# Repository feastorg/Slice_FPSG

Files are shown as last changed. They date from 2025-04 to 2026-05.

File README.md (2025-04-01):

# Slice Template

Template for creating BREAD slices.

## Introduction

[Short introduction on the project.]

## Usage

[Explain how to use the project. Include examples and screenshots if applicable.]

## Documentation

Please refer to the [docs](/docs) for more info.

---

<div align="center">
  <p>
    
    
  </p>
</div>

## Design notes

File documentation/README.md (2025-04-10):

# Docs

Main page for the documentation of the project.

## Schematic Design Notes

Notes on design.

### External Clock

- **Oscillator:** ACO-8.000MHZ-EK

  - 8 MHz XO (Standard) HCMOS, TTL Oscillator, 5V enable/disable
  - Package: 14-DIP, 4 Leads (Metal Can)
  - Product: (See Digikey)
  - Procurement: [Digikey](https://www.digikey.ca/short/9n0brwjd)
  - Datasheet: [Abracon ACO Datasheet](https://abracon.com/Oscillators/ACO.pdf)

- **Connection:**

  - Powered by a dedicated, low-noise 5V rail (from a TPS7A4901 set to 5V)
  - Feed clock output to:
    - ADC’s CLKIN/XTAL1 pin (XTAL2 left unconnected or per datasheet recommendation)
    - Nano Every’s external clock input (D2/PA00 on the ATmega4809)
  - Ensures ADC’s modulator clock and MCU SPI SCLK are synchronous
  - Reference: [Nano Every External Oscillator Info - Arduino Subreddit](https://www.reddit.com/r/arduino/comments/vyi9wo/using_an_external_oscillator_with_the_nano_every/)

    - The onboard programmer on the Nano Every is fully independent and does not rely on bootloaders or clock speed restrictions like the Atmega328-based Arduinos.
    - You don’t need to set fuses via the Arduino IDE; instead, the clock source can be configured at runtime.
    - To change the clock source to external (PA00, Arduino pin D2), use the following code snippet:

      ```
      CPU_CCP = 0xD8;           // Enable writing to protected config registers for the next 4 cycles
      CLKCTRL.MCLKCTRLA = 0x03; // Set clock output off, select external clock source (PA00)
      ```

### Instrumentation Amplifier

- **Amplifier:** AD8426
  - Dual instrumentation amplifier (2 channels per package; use 4 for 8 channels)
  - Product: [AD8426](https://www.analog.com/en/products/ad8426.html)
  - Procurement: [Digikey](https://www.digikey.ca/short/vj3493t8)
  - Datasheet: [AD8426 Datasheet](https://www.analog.com/media/en/technical-documentation/data-sheets/AD8426.pdf)

- **REF Pin:**
  - Maintain low source impedance (<2 Ω recommended)
  - Use a buffered reference (OP1177, see below)

### Analog Reference Voltage Sources

- **Main Regulator (Analog Front End):** TPS7A4901DGNR
  - 150-mA, 36-V, low-noise, high-PSRR adjustable LDO
  - Provides VAA (analog supply) adjustable between ~5V and 10V (up to 12V from a 12V input)
  - Product: [TPS7A4901DGNR](https://www.ti.com/product/TPS7A49/part-details/TPS7A4901DGNR)
  - Procurement: [Digikey](https://www.digikey.ca/short/hr5vft5w)
  - Datasheet: [TPS7A49 Datasheet](https://www.ti.com/lit/ds/symlink/tps7a49.pdf)

- **Clock Regulator:**
  - A second TPS7A4901 (configured to output a fixed 5V) provides the dedicated, low-noise 5VA rail for the external oscillator.

- **Grounding:**
  - Analog ground (gnd_a) is kept separate from digital ground, but tied at a star point.

### Analog Midsupply Voltage Source

- **Reference Buffer:** OP1177 (e.g., OP1177ARMZ)
  - Precision, low-noise op amp used to buffer a resistor divider (with a multi-turn pot) to generate a tunable mid-supply voltage (VREF)
  - Provides a high-impedance reference for the REF pins on the AD8426 amplifiers
  - Product: [OP1177](https://www.analog.com/en/products/op1177.html)
  - Procurement: [Mouser](https://mou.sr/3E6iI69)
  - Datasheet: [OP1177 Datasheet](https://www.analog.com/media/en/technical-documentation/data-sheets/op1177_2177_4177.pdf)

- **Implementation:**
  - Typically one buffered reference can drive all REF pins if layout is good; otherwise, consider one per AD8426.

### Antialiasing Filtering

- Simple RC circuits

### External ADC

- **ADC:** ADS131M08IPBS
  - 24-bit, 32-kSPS, 8-channel simultaneous delta-sigma ADC
  - Product: [ADS131M08](https://www.ti.com/product/ADS131M08)
  - Procurement: [Mouser](https://mou.sr/4j7vdgE)
  - Datasheet: [ADS131M08 Datasheet](https://www.ti.com/lit/ds/symlink/ads131m08.pdf)

### Load Cell

- **MODEL 1914A FEMUR LOAD CELL**
- **Overview:**
  - Provides comprehensive measurements of forces acting on the upper leg just above the knee joint.
  - Features six measurement channels—three forces and three moments—each implemented as a full-bridge strain gauge circuit.
- **Excitation:**
  - Typical excitation is 10 V (nominal), up to 15 V max.
- **Additional Information:**
  - Detailed wiring, specifications, and calibration info are available in the separate Load Cell Datasheet.
  - See [load_cell_specs.md](./load_cell_specs.md) for complete specifications and wiring details (datasheet summary).

### SPI & Data Logging

- **SPI Data Capture:**
  - High-speed SPI data from the ADC is captured by the ATmega4809 (Nano Every)
  - Utilize DMA to transfer data to a buffer
- **Data Logging:**
  - Logging to an SD card (via a high-speed SPI/SDIO interface) and/or real-time USB streaming

## Style Guide

### KiCad Power Symbols Legend

| Power Symbol | Designation | Reference |
| --- | --- | --- |
| +12V | 12V | 12V Source Supply (from the 12V rail on the backplane) |
| GND | GND | Common Ground (from the 12V rail's GND on the backplane) |
| +5V | 5V | Digital 5V Supply (generated by the buck converter for digital circuits) |
| +5VA | 5VA | Dedicated 5V Supply for the external clock oscillator (low-noise LDO output) |
| VAA | VAA | Analog Front-End Supply (adjustable, 5–10V, for sensor conditioning, amps) |
| VPP-->VMID | VMID | _Renamed VPP symbol to VMID._ Mid-Supply Reference Voltage (buffered via OP1177 for instrumentation amps) |
| GNDA | AGND | Analog Ground (for sensor, amps, ADC; tied at star point with DGND) |
| GNDD | DGND | Digital Ground (connected to common ground through heatsink pad) |

### KiCad Colors Legend

| Color  | Value | Reference |
| --- | --- | --- |
| Red | red3 | Analog 5V Supply (e.g., for amps, ADC, references) |
| Brown  | orange1  | Analog Ground (sensor/amp/ADC ground) |
| Orange | orange3  | Digital 5V Supply (MCU, digital circuits) |
| Black  | black | Digital Ground (MCU ground) |
| Pink | magenta3 | 12V Source Supply (from 12V rail on backplane) |
| Blue | blue3 | Clock Signals (oscillator, ADC CLKIN, SPI SCLK) |
| Green  | green3 | Analog Signals (amp outputs to ADC + inputs) |
| Yellow | yellow3  | SPI Control (CS, SYNC/RESET, etc.) |
| Purple | #A020F0  | Special/Reference/Control Signals |
| Grey | gray2 | Miscellaneous/Unassigned |
| Teal | cyan2 | Template/Backplane Connections |

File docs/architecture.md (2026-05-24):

---
title: "Architecture"
description: "Hardware and firmware architecture overview."
---

# Architecture

## Hardware

Full-bridge Precision Strain Gauge (PSG) amplifier/conditioning slice (4-layer PCB). Uses AD8426 instrumentation amplifier with TPS7A4901 precision regulator.

## Firmware

_Not yet developed._

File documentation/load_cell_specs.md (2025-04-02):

# Load Cell Datasheet Details (Model 1914A Femur Load Cell)

**Issue Date:** 5 December 2002

**Models:**  
1914A (and related models: HII 50M, HIII 95LM, HIII 50M, HIII 5F, THOR, BioSID, SID, EuroSID-1, SID-IIs, ES-2)  
_Note: Models 1914V and 1914 Femur Load Cells are identical except for bridge resistance._

- We have 1914A

**Applications:**

- Measures forces on the upper leg above the knee joint
- Useful for occupant protection systems (e.g., knee bolsters)
- Adaptable via removable/replacement end caps
- Contains six measurement channels: three forces and three moments
- Two 30-foot (9.15 m), 12-conductor, Teflon insulated, shielded cables exit the load cell (one for force channels, one for moment channels)
- With aluminum end caps (part #5632), can be used in the ES-2

**Specifications:**

| Channel | Capacity (Metric) | Capacity (English) | Bridge Resistance (1914) | Bridge Resistance (1914A) | Bridge Resistance (1914V) | Sensitivity (mv/v) |
| --- | --- | --- | --- | --- | --- | --- |
| Fx | 13,344.7 N | 3,000 lb | 350 Ω | 350 Ω | 120 Ω | 1.8 |
| Fy | 13,344.7 N | 3,000 lb | 350 Ω | 350 Ω | 120 Ω | 1.8 |
| Fz | 22,241.1 N | 3,000 lb | 480 Ω | 700 Ω | 120 Ω | 1.2 |
| Mx | 338.9 Nm | 3,000 in-lb | 350 Ω | 350 Ω | 120 Ω | 1.5 |
| My | 338.9 Nm | 3,000 in-lb | 350 Ω | 350 Ω | 120 Ω | 1.5 |
| Mz | 338.9 Nm | 3,000 in-lb | 700 Ω | 700 Ω | 240 Ω | 2.6 |

- **Nonlinearity:** < 1% of full scale
- **Hysteresis:** < 1% of full scale
- **Crosstalk:** < 5% of full scale
- **Excitation:** 10 VDC nominal, up to 15 VDC max
- **Mass:** 1.043 kg (2.3 lb)

**Wiring (per channel group):**

| Channel Group | +Excitation | +Signal | -Excitation | -Signal |
| --- | --- | --- | --- | --- |
| Fx & Mx Channels | Brown | Red | Orange | Yellow |
| Fy & My Channels | Red Stripe  | Black | White | Black Stripe |
| Fz & Mz Channels | Green | Blue | Violet | Gray |

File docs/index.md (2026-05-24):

---
title: "Slice FPSG Documentation"
description: "Overview and entry page for Slice FPSG project documentation."
nav_exclude: true
---

Welcome to the Slice FPSG project documentation.

## Board Renders

<figure style="display:inline-block; text-align:center; margin:10px;">
  Board Top
  <figcaption>Top</figcaption>
</figure>

<figure style="display:inline-block; text-align:center; margin:10px;">
  Board Bottom
  <figcaption>Bottom</figcaption>
</figure>

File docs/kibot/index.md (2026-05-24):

---
title: "KiBot Outputs"
description: "Index for KiBot-generated PCB artifacts."
layout: "page"
---

These are the docs & KiBot Outputs for Slice FPSG

The following files were generated from the latest PCB build:

_(Not yet generated — will be populated by CI on first successful run.)_

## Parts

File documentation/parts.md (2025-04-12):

# Parts Dump

- M12 circular board connector:
  - https://www.mouser.ca/ProductDetail/Phoenix-Contact/1439890?qs=MfVUZiz0PxY5wYKCjWFERg%3D%3D
  - looking down cable:

```
   Exc+ (1)    Sig+ (2)
      ●           ●

   Exc− (3)    Sig− (4)
      ●           ●
```

- SD Card holder
  - https://www.digikey.ca/en/products/detail/molex/0472192001/3044807?s=N4IgTCBcDaICwHYwEYCcBaMAGLyQF0BfIA

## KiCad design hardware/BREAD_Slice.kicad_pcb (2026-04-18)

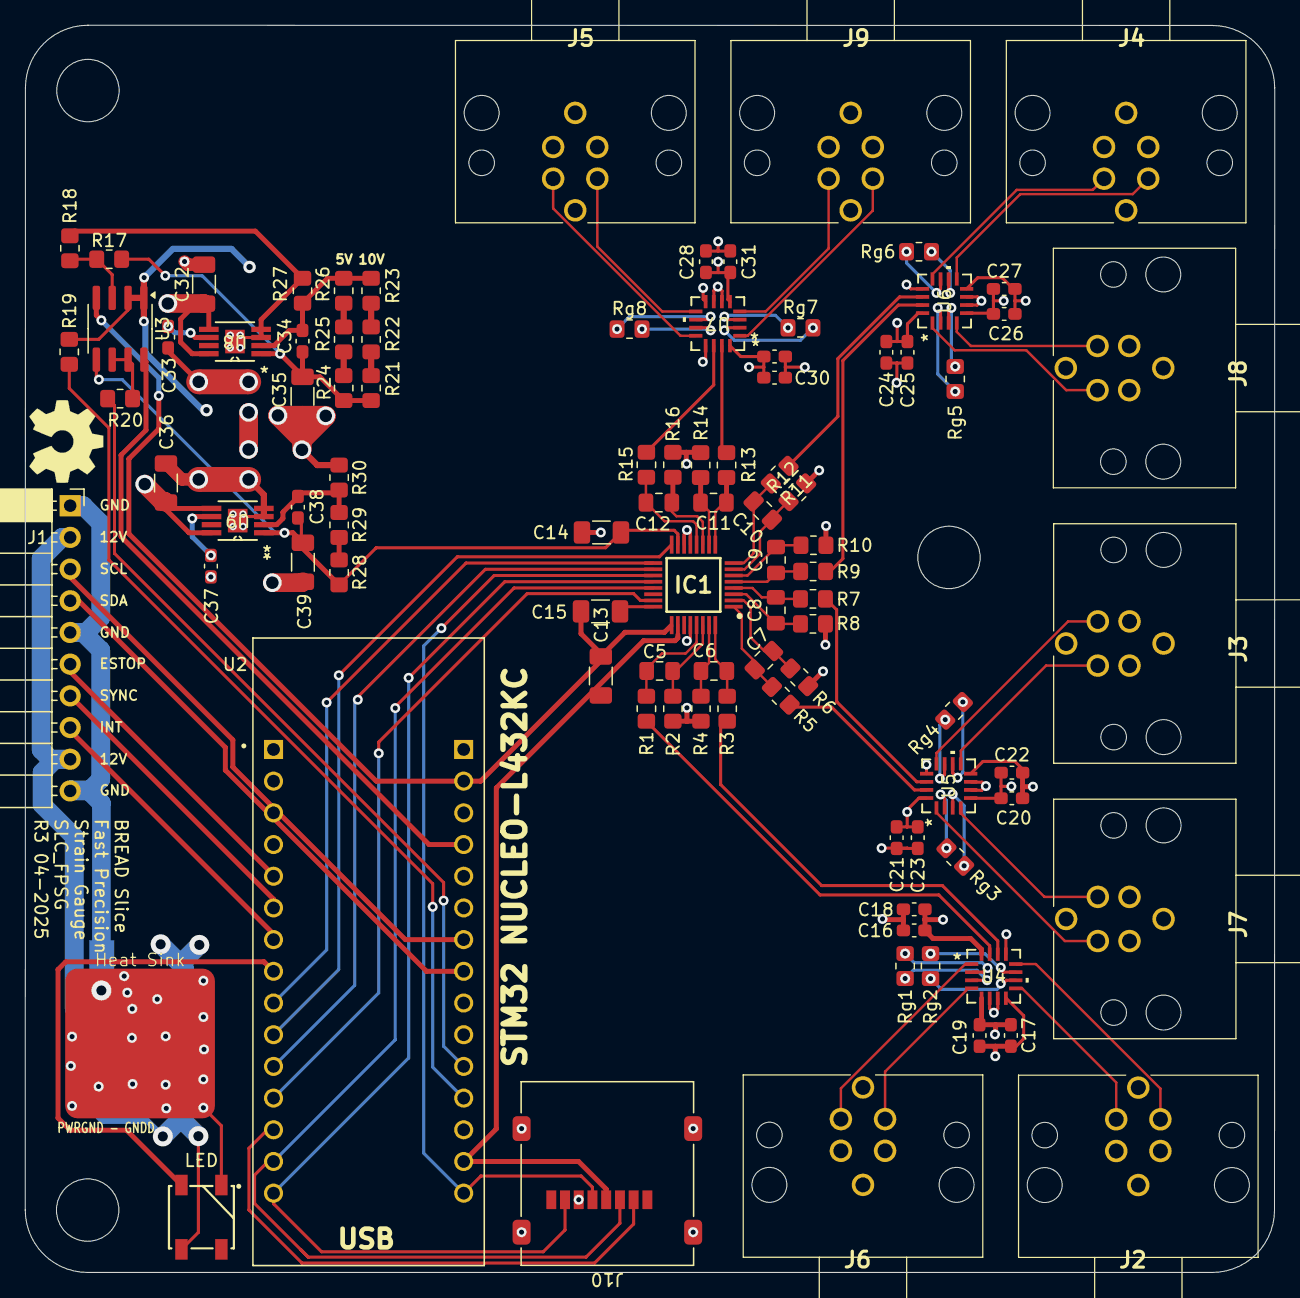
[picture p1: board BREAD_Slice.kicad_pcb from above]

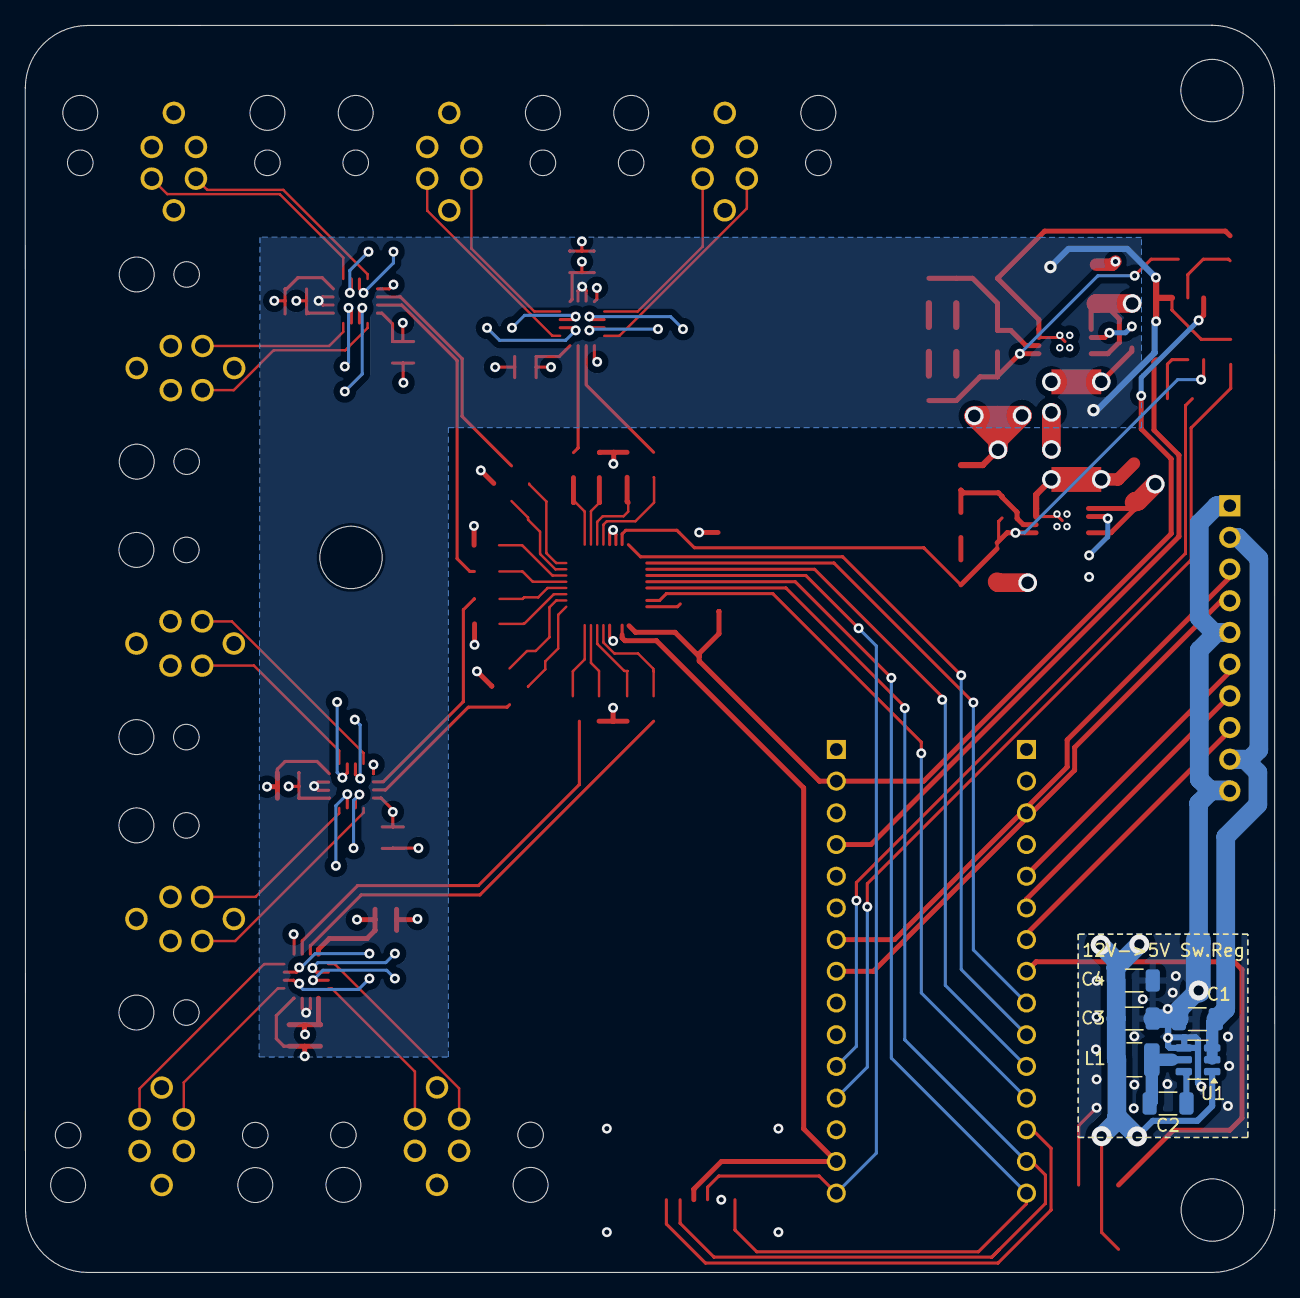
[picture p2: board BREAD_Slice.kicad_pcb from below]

Board: 4 copper layers, 100.1 x 100.0 mm, 107 parts (7 on the bottom side), 95 nets.

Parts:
C1, C3, C4: 22uF; C_1206_3216Metric
C2: 100nF; C_1206_3216Metric
C5, C6, C7, C8, C9, C10, C11, C12: 10n; C_0805_2012Metric_Pad1.18x1.45mm_HandSolder
C13, C14: 1u; C_1206_3216Metric_Pad1.33x1.80mm_HandSolder
C15: 220n; C_1206_3216Metric_Pad1.33x1.80mm_HandSolder
C16, C18, C20, C22, C24, C26, C28, C30: 1u; C_0603_1608Metric_Pad1.08x0.95mm_HandSolder
C17, C19, C21, C23, C25, C27, C29, C31: 10u; C_0603_1608Metric_Pad1.08x0.95mm_HandSolder
C32, C35, C36, C39: 10u X7R; C_1206_3216Metric_Pad1.33x1.80mm_HandSolder
C33, C34, C37, C38: 10n X7R; C_0603_1608Metric_Pad1.08x0.95mm_HandSolder
D1: WS2812B_5050; WS2812-5050-4PIN
H1, H2, H3: MountingHole; MountingHole_5mm
HS1: Heatsink_Pad; Thermal Pad
IC1: ADS131M08IPBS; QFP50P700X700X120-32N
J1: Conn_01x10_Female; PinSocket_1x10_P2.54mm_Horizontal
J2, J3, J4, J5, J6, J7, J8, J9: 1439890
J10: Micro_SD_Card; microSD_HC_Molex_47219-2001
L1: 4.7uH; L_1210_3225Metric
Logo1: Logo_Open_Hardware_Small; OSHW-Symbol_6.7x6mm_SilkScreen
NT1, NT2, NT3: NetTie_2; NetTie-2_SMD_Pad2.0mm
R1, R2, R3, R4, R5, R6, R7, R8, R9, R10, R11, R12, R13, R14, R15, R16, R19, R20: 1k; R_0805_2012Metric_Pad1.20x1.40mm_HandSolder
R17, R18: 50k 1%; R_0805_2012Metric_Pad1.20x1.40mm_HandSolder
R21: 680 1%; R_0805_2012Metric_Pad1.20x1.40mm_HandSolder
R22: 680k 1%; R_0805_2012Metric_Pad1.20x1.40mm_HandSolder
R23: 63.4k 1%; R_0805_2012Metric_Pad1.20x1.40mm_HandSolder
R24: 100 1%; R_0805_2012Metric_Pad1.20x1.40mm_HandSolder
R25, R28: 300k 1%; R_0805_2012Metric_Pad1.20x1.40mm_HandSolder
R26, R29: 71.5k 1%; R_0805_2012Metric_Pad1.20x1.40mm_HandSolder
R27, R30: 100k 1%; R_0805_2012Metric_Pad1.20x1.40mm_HandSolder
Rg1, Rg2, Rg3, Rg4, Rg5, Rg6, Rg7, Rg8: -; R_0805_2012Metric_Pad1.20x1.40mm_HandSolder
U1: AP63205; TSOT-23-6
U2: NUCLEO-L432KC; MODULE_NUCLEO-L432KC
U3: MCP6022; SOIC-8_3.9x4.9mm_P1.27mm
U4, U5, U6, U7: AD8426BCPZ-WP; CP_16_19_ADI
U8, U9: TPS7A4901DGNR; DGN8_1P89X1P57

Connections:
+3.3VADC: C14.2, C38.2, C39.2, IC1.15 (AVDD), R28.2, U3.5 (+), U9.1 (OUT)
+3V3: C13.2, IC1.26 (DVDD), J10.4 (VDD), U2.CN4_14 (+3V3)
+5VD: C3.2, C4.2, D1.1 (VDD), L1.2, U1.1 (FB), U2.CN4_4 (+5V), U3.8 (V+)
+12V: C1.2, C32.2, C36.2, J1.2, J1.9, U1.2 (EN), U1.3 (VIN), U8.5 (EN), U8.8 (IN), U9.5 (EN), U9.8 (IN)
/ADC_CS: IC1.17 (~CS), U2.CN3_9 (PB1)
/CLK_MCO: IC1.23 (XTAL1/CLKIN), U2.CN3_12 (PA8)
/DRDY: IC1.18 (~DRDY), U2.CN3_11 (PC15)
/ESTOP: J1.6, U2.CN3_5 (PA12)
/I2C_CLK: J1.3, U2.CN4_7 (PA6)
/I2C_DAT: J1.4, U2.CN4_8 (PA5)
/IN0+: C5.2, IC1.29 (AIN0P), R1.1
/IN0-: C5.1, IC1.30 (AIN0N), R2.1
/IN1+: C6.2, IC1.32 (AIN1P), R3.1
/IN1-: C6.1, IC1.31 (AIN1N), R4.1
/IN2+: C7.2, IC1.1 (AIN2P), R5.1
/IN2-: C7.1, IC1.2 (AIN2N), R6.1
/IN3+: C8.2, IC1.4 (AIN3P), R7.1
/IN3-: C8.1, IC1.3 (AIN3N), R8.1
/IN4+: C9.2, IC1.5 (AIN4P), R9.1
/IN4-: C9.1, IC1.6 (AIN4N), R10.1
/IN5+: C10.2, IC1.8 (AIN5P), R11.1
/IN5-: C10.1, IC1.7 (AIN5N), R12.1
/IN6+: C11.2, IC1.9 (AIN6P), R13.1
/IN6-: C11.1, IC1.10 (AIN6N), R14.1
/IN7+: C12.2, IC1.12 (AIN7P), R15.1
/IN7-: C12.1, IC1.11 (AIN7N), R16.1
/INT: J1.7, U2.CN3_6 (PB0)
/LC0_SIG+: J6.1, U4.4 (+IN1)
/LC0_SIG-: J6.2, U4.1 (-IN1)
/LC1_SIG+: J2.2, U4.9 (+IN2)
/LC1_SIG-: J2.1, U4.12 (-IN2)
/LC2_SIG+: J7.1, U5.4 (+IN1)
/LC2_SIG-: J7.2, U5.1 (-IN1)
/LC3_SIG+: J3.2, U5.9 (+IN2)
/LC3_SIG-: J3.1, U5.12 (-IN2)
/LC4_SIG+: J8.1, U6.4 (+IN1)
/LC4_SIG-: J8.2, U6.1 (-IN1)
/LC5_SIG+: J4.2, U6.9 (+IN2)
/LC5_SIG-: J4.1, U6.12 (-IN2)
/LC6_SIG+: J9.1, U7.4 (+IN1)
/LC6_SIG-: J9.2, U7.1 (-IN1)
/LC7_SIG+: J5.2, U7.9 (+IN2)
/LC7_SIG-: J5.1, U7.12 (-IN2)
/LED: D1.4 (DIN), U2.CN3_8 (PB6)
/MISO: IC1.20 (DOUT), J10.7 (DAT0), U2.CN3_15 (PB4)
/MOSI: IC1.21 (DIN), J10.3 (CMD), U2.CN3_14 (PB5)
/OUT0: R1.2, U4.15 (OUT1)
/OUT1: R3.2, U4.14 (OUT2)
/OUT2: R5.2, U5.15 (OUT1)
/OUT3: R7.2, U5.14 (OUT2)
/OUT4: R9.2, U6.15 (OUT1)
/OUT5: R11.2, U6.14 (OUT2)
/OUT6: R13.2, U7.15 (OUT1)
/OUT7: R15.2, U7.14 (OUT2)
/RST_ADC: IC1.16 (~SYNC/~RESET), U2.CN3_10 (PC14)
/SCK: IC1.19 (SCLK), J10.5 (CLK), U2.CN4_15 (PB3)
/SD_CS: J10.2 (DAT3/CD), U2.CN3_13 (PA11)
/SYNC: J1.8, U2.CN3_7 (PB7)
/TPS7A4901-VAA/FB: C34.1, R23.1, R26.1, R27.2, U8.2 (FB)
/VADC_SENS: R20.2, U2.CN4_11 (PA1)
/VMID: R19.1, U3.1, U3.2 (-), U4.6 (REF1), U4.7 (REF2), U5.6 (REF1), U5.7 (REF2), U6.6 (REF1), U6.7 (REF2), U7.6 (REF1), U7.7 (REF2)
/VMID_SENS: R19.2, U2.CN4_12 (PA0)
GNDA: C14.1, C16.2, C17.2, C18.2, C19.2, C20.2, C21.2, C22.2, C23.2, C24.2, C25.2, C26.2, C27.2, C28.2, C29.2, C30.2, C31.2, C35.1, C39.1, IC1.13 (AGND_1), IC1.14 (REFIN), IC1.28 (AGND_2), J2.4, J2.5, J2.6, J3.4, J3.5, J3.6, J4.4, J4.5, J4.6, J5.4, J5.5, J5.6, J6.3, J6.5, J6.6, J7.3, J7.5, J7.6, J8.3, J8.5, J8.6, J9.3, J9.5, J9.6, NT2.2, NT3.2, R2.2, R4.2, R6.2, R8.2, R10.2, R12.2, R14.2, R16.2, R18.2, R27.1, R30.1, U4.8 (-VS), U4.13 (-VS), U5.8 (-VS), U5.13 (-VS), U6.8 (-VS), U6.13 (-VS), U7.8 (-VS), U7.13 (-VS), U8.3 (NC), U8.4 (GND), U8.EPAD, U9.3 (NC), U9.4 (GND), U9.EPAD
GNDD: C1.1, C3.1, C4.1, C13.1, C15.1, D1.3 (VSS), HS1.1, IC1.25 (DGND), J10.6 (VSS), J10.9 (SHIELD), NT1.2, U1.4 (GND), U2.CN3_4 (GND_CN3), U2.CN4_2 (GND_CN4), U3.4 (V-)
GNDPWR: C32.1, C33.1, C36.1, C37.1, J1.1, J1.5, J1.10, NT1.1, NT2.1, NT3.1
unnamed: C15.2, IC1.24 (CAP)
unnamed: R21.1, R22.2
unnamed: R22.1, R23.2
unnamed: R24.1, R25.2
unnamed: R25.1, R26.2
unnamed: R28.1, R29.2
unnamed: Rg1.1, U4.3 (RG1)
unnamed: Rg1.2, U4.2 (RG1)
unnamed: Rg2.1, U4.10 (RG2)
unnamed: Rg2.2, U4.11 (RG2)
unnamed: Rg3.1, U5.3 (RG1)
unnamed: Rg3.2, U5.2 (RG1)
unnamed: Rg4.1, U5.10 (RG2)
unnamed: Rg4.2, U5.11 (RG2)
unnamed: Rg5.1, U6.3 (RG1)
unnamed: Rg5.2, U6.2 (RG1)
unnamed: Rg6.1, U6.10 (RG2)
unnamed: Rg6.2, U6.11 (RG2)
unnamed: Rg7.1, U7.3 (RG1)
unnamed: Rg7.2, U7.2 (RG1)
unnamed: Rg8.1, U7.10 (RG2)
unnamed: Rg8.2, U7.11 (RG2)
unnamed: C2.2, U1.6 (BST)
unnamed: C2.1, L1.1, U1.5 (SW)
unnamed: R17.2, R18.1, U3.3 (+)
unnamed: R20.1, U3.6 (-), U3.7
unnamed: C33.2, U8.6 (NR/SS)
unnamed: C38.1, R29.1, R30.2, U9.2 (FB)
unnamed: C37.2, U9.6 (NR/SS)
VAA: C16.1, C17.1, C18.1, C19.1, C20.1, C21.1, C22.1, C23.1, C24.1, C25.1, C26.1, C27.1, C28.1, C29.1, C30.1, C31.1, C34.2, C35.2, J2.3, J3.3, J4.3, J5.3, J6.4, J7.4, J8.4, J9.4, R17.1, R21.2, R24.2, U4.5 (+VS), U4.16 (+VS), U5.5 (+VS), U5.16 (+VS), U6.5 (+VS), U6.16 (+VS), U7.5 (+VS), U7.16 (+VS), U8.1 (OUT)

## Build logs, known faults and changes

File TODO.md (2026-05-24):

# Slice_FPSG TODO

## CI Results (Pass 1)

- [x] DRC: FAIL — 4 errors (2x shorting_items: nets shorting I2C_CLK and I2C_DAT, 2x solder_mask_bridge: front mask bridges different nets)
- [x] ERC: FAIL (blocked by DRC errors)
- [x] Fab: FAIL (blocked by DRC errors)
- [ ] gen-kibot-index: SKIPPED (upstream failed)
- [ ] deploy-pages: SKIPPED (upstream failed)

**Note: 4-layer board (In1.Cu/In2.Cu enabled in kibot config)**

## Pass 2 – Pre-fab Review

- [ ] Fix 2x shorting items (I2C_CLK, I2C_DAT shorted to unnamed net)
- [ ] Fix 2x solder mask bridge (front mask aperture bridges different nets)
- [ ] Verify BOM completeness
- [ ] Confirm board outline and mounting holes
- [ ] Update README.md (still says "Slice Template")

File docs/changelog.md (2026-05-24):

---
title: "Changelog"
description: "Hardware and firmware revision history."
---

# Changelog

## Hardware

### v0.1.0 (initial)
- Initial schematic and PCB layout (4-layer)
- AD8426 PSG amplifier sub-circuit
- TPS7A4901 adjustable regulator sub-circuit
- Full-bridge load cell interface

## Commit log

2025-04-01 initial commit of hw
    [AD8426_PSG.kicad_sch, BREAD_Slice.kicad_sch, BREAD_Slice_Conn.kicad_pcb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]
2025-04-02 updated some docs
    [AD8426_PSG.kicad_sch, BREAD_Slice.kicad_sch, tps7a4901.kicad_sch]
2025-04-10 finalize board before switch to stm
    [AD8426_PSG.kicad_sch, BREAD_Slice.kicad_sch, fb_load_cell.kicad_sch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]
2025-04-12 final iteration of board with proper connectors and clean layout
    [BREAD_Slice.kicad_pcb, BREAD_Slice.kicad_sch, fb_load_cell.kicad_sch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]
2026-04-18 chore: export gerbers
    [BREAD_Slice-B_Cu.gbr, BREAD_Slice-B_Mask.gbr, BREAD_Slice-B_Paste.gbr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]
